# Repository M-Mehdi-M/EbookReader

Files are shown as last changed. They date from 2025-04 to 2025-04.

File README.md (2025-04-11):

## MAHMOUDI Mohammadmehdi 332CB 

# Description
EbookReader is an open-source hardware development platform featuring an E-Paper display, environmental sensing, and low-power connectivity options. Perfect for IoT projects, information displays, and environmental monitoring applications.

## 📋 Overview
This project provides a complete hardware platform built around the ESP32-C6 microcontroller with built-in WiFi 6 and Bluetooth 5 LE connectivity. The E-Paper display offers excellent visibility in various lighting conditions with minimal power consumption.

## 🔌 Hardware Architecture and Components

- **Microcontroller**: ESP32-C6-WROOM-1-N8
  - RISC-V core with WiFi 6 and Bluetooth 5 LE
  - Operating at 3.3V

- **Display**: E-Paper display module
  - SPI interface
  - Ultra-low power consumption when not refreshing

- **Storage**: 
  - microSD card slot (SPI)
  - 64MB External NOR Flash (W25Q512JVEIQ)

- **Sensors**:
  - BME688 Environmental sensor (temperature, humidity, pressure, gas)
  - Battery voltage monitoring

- **Power Management**:
  - Li-Po battery charging circuit
  - Fuel gauge (MAX17048G+T10)
  - Low dropout regulator (XC6220A331MR-G)
  - Deep sleep current <10μA

- **Timekeeping**:
  - DS3231SN RTC with temperature compensation

### Expansion Options
- Qwiic/Stemma QT connector for I²C peripherals
- Test pads for debugging

## 🔧 Development Guide

### Getting Started
1. Install the ESP-IDF development framework
2. Clone this repository
3. Connect the board via USB-C
4. Build and flash using ESP-IDF commands

### Example Applications
- Weather station
- Calendar display
- E-ink dashboard
- IoT sensor node
- Low-power data logger

## 📐 Hardware Design Files
The hardware design includes:
- Schematic
- PCB layout
- Bill of Materials
- 3D models of critical components

### Design Notes
- ESD protection on all external interfaces
- Carefully designed power distribution
- Signal integrity considerations for SPI bus
- Separate power domain for E-Paper

## 🔋 Battery Management
- Built-in Li-ion battery charging
- Battery level monitoring
- Low-battery detection and safe shutdown
- Optimized power design for long battery life

## 🛠️ Implementation Steps
1. Review schematic and understand all interfaces
2. Generate PCB layout from schematic
3. Implement power planes and critical routing
4. Add custom design rules for manufacturing
5. Place and route all signals
6. Add 3D models for visualization and mechanical fit

## ✅ Safety Features
- Overcurrent protection
- Reverse polarity protection
- ESD protection on external interfaces
- Thermal management for charging circuit

You can view the "BOM" file [here](Manufacturing/BOM.csv)

You can view the "PICK and PLACE" file [here](Manufacturing/Pick_&_Place.csv)

## 📖 Resources
- [Design & Implementation Guide](https://ocw.cs.pub.ro/courses/tsc/proiect2025)
- [ESP32-C6 Datasheet](https://www.espressif.com/sites/default/files/documentation/esp32-c6_datasheet_en.pdf)

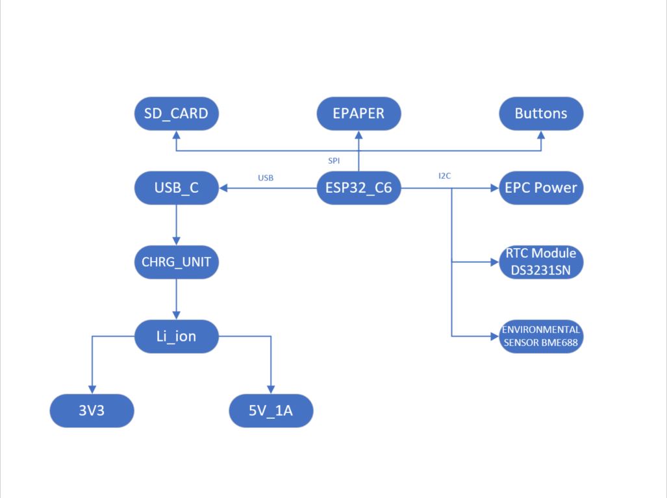
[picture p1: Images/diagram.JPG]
Diagram Image


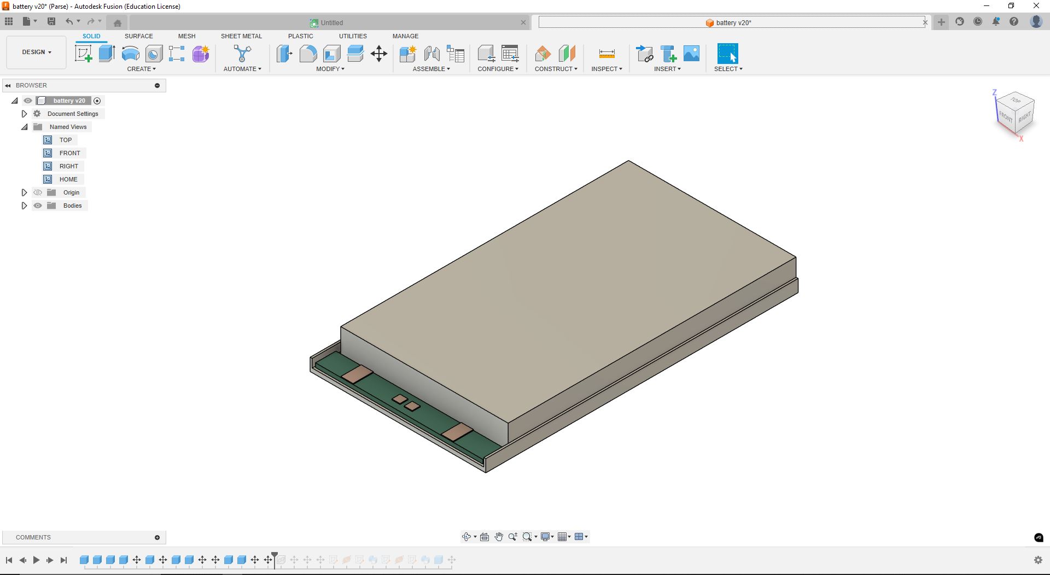
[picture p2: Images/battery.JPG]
Battery Image


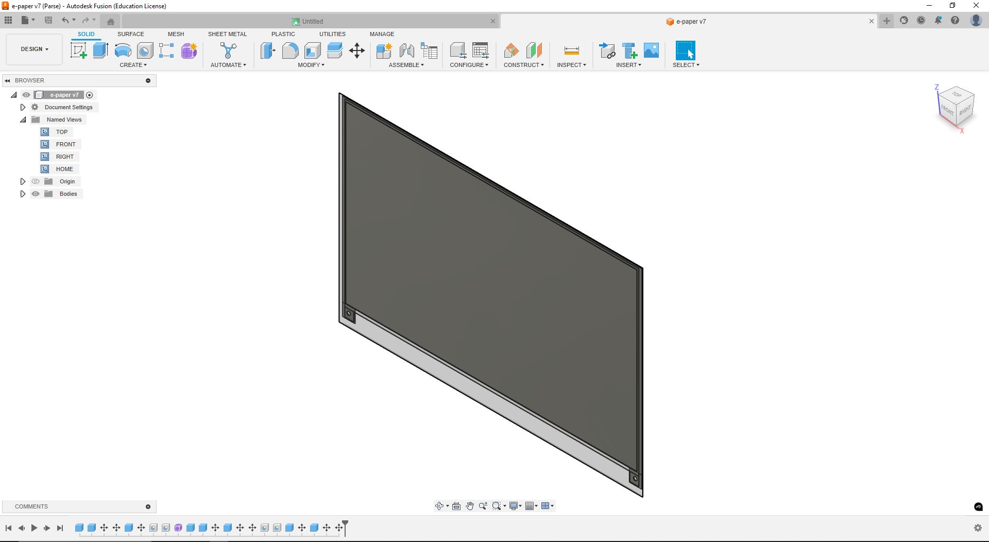
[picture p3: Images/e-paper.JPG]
E_paper Image


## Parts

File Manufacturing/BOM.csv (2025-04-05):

Qty | Value | Device | Package | Parts | Description | ARROW_PART_NUMBER | ARROW_PRICE-STOCK | AVAILABILITY | CENTROID_NOT_SPECIFIED | CHECK_PRICES | COPYRIGHT | DATASHEET | DESCRIPTION | DIGIKEY_DESCRIPTION | DIGIKEY_PART_NUMBER | HEIGHT | LEAD_FREE | MANUFACTURER_NAME | MANUFACTURER_PART_NUMBER | MF | MFR_NAME | MOUSER_PART_NUMBER | MOUSER_PRICE-STOCK | MOUSER_TESTING_PART_NUMBER | MOUSER_TESTING_PRICE-STOCK | MP | MPN | PACKAGE | POPULARITY | PREFIX | PRICE | PROD_ID | PURCHASE-URL | ROHS | SNAPEDA_LINK | SPICEMODEL | SPICEPREFIX | TEMPERATURE_RANGE_HIGH | TEMPERATURE_RANGE_LOW | TP_SIGNAL_NAME | VALUE
1 |  | ADAFRUIT_LEDCHIP-LED0603 | ADAFRUIT_CHIP-LED0603 | CHG_LED | LED
1 |  | ESP32C6_VARISTORCN1812 | ESP32C6_VARISTOR_CT/CN1812 | PFMF.050.1 | VARISTOR |  |  |  |  |  |  |  |  |  |  |  |  |  |  |  |  |  |  |  |  |  |  |  | 0
1 |  | SAMACSYS_PARTS_USB4110-GF-A | SAMACSYS_PARTS_USB4110GFA | J2 | CONN USB 2.0 TYPE-C R/A SMT |  |  |  |  |  |  |  | CONN USB 2.0 TYPE-C R/A SMT |  |  | 3.26mm |  | GCT (GLOBAL CONNECTOR TECHNOLOGY) | USB4110-GF-A |  |  | 640-USB4110-GF-A | https://www.mouser.co.uk/ProductDetail/GCT/USB4110-GF-A?qs=KUoIvG%2F9IlYiZvIXQjyJeA%3D%3D
1 |  | SJ | SJ | SJ1 | SMD solder JUMPER |  |  |  |  |  |  |  |  |  |  |  |  |  |  |  |  |  |  |  |  |  |  |  | 3
1 | 100nF | ESP32_WROVER_EAGLE-LTSPICE_CC0402 | ESP32_WROVER_EAGLE-LTSPICE_C0402 | C10 | CAPACITOR, European symbol |  |  |  |  |  |  |  |  |  |  |  |  |  |  |  |  |  |  |  |  |  |  |  |  |  |  |  |  |  |  | NONE | C
1 | 0.1uF/50V | ESP32_WROVER_EAGLE-LTSPICE_CC0402 | ESP32_WROVER_EAGLE-LTSPICE_C0402 | EPD_C5 | CAPACITOR, European symbol |  |  |  |  |  |  |  |  |  |  |  |  |  |  |  |  |  |  |  |  |  |  |  |  |  |  |  |  |  |  | NONE | C
1 | 0.47 | ESP32_WROVER_EAGLE-LTSPICE_RR0402 | ESP32_WROVER_EAGLE-LTSPICE_R0402 | R3 | RESISTOR, European symbol |  |  |  |  |  |  |  |  |  |  |  |  |  |  |  |  |  |  |  |  |  |  |  |  |  |  |  |  |  |  | NONE | R
1 | 100K | ESP32_WROVER_EAGLE-LTSPICE_RR0402 | ESP32_WROVER_EAGLE-LTSPICE_R0402 | R1_PWRUSB | RESISTOR, European symbol |  |  |  |  |  |  |  |  |  |  |  |  |  |  |  |  |  |  |  |  |  |  |  |  |  |  |  |  |  |  | NONE | R
1 | 100nF | EAGLE-LTSPICE_CC0402 | EAGLE-LTSPICE_C0402 | C4_USB | CAPACITOR, European symbol |  |  |  |  |  |  |  |  |  |  |  |  |  |  |  |  |  |  |  |  |  |  |  |  |  |  |  |  |  |  | NONE | C
6 | 100nF | ESP32_WROVER_EAGLE-LTSPICE_CC0402 | ESP32_WROVER_EAGLE-LTSPICE_C0402 | C1, C2, C6, C8, C9, C_DELAY | CAPACITOR, European symbol |  |  |  |  |  |  |  |  |  |  |  |  |  |  |  |  |  |  |  |  |  |  |  |  |  |  |  |  |  |  | NONE | C
1 | 100uF TANT | RCL_CPOL-EUCT3528 | RCL_CT3528 | C3 | POLARIZED CAPACITOR, European symbol |  |  |  |  |  |  |  |  |  |  |  |  |  |  |  |  |  |  |  |  |  |  |  | 0 |  |  |  |  |  |  |  | C
16 | 10K | ESP32_WROVER_EAGLE-LTSPICE_RR0402 | ESP32_WROVER_EAGLE-LTSPICE_R0402 | R1, R1_PINH, R1_PINH1, R2-PINH, R2-PINH1, R4, R5, R6, R7, R8, R9, R10, R_BOOT, R_CHANGE, R_CL1, R_RESET | RESISTOR, European symbol |  |  |  |  |  |  |  |  |  |  |  |  |  |  |  |  |  |  |  |  |  |  |  |  |  |  |  |  |  |  | NONE | R
1 | 10uF | ESP32_WROVER_EAGLE-LTSPICE_CC0402 | ESP32_WROVER_EAGLE-LTSPICE_C0402 | C7 | CAPACITOR, European symbol |  |  |  |  |  |  |  |  |  |  |  |  |  |  |  |  |  |  |  |  |  |  |  |  |  |  |  |  |  |  | NONE | C
1 | 112A-TAAR-R03_ATTEND | 112A-TAAR-R03_ATTEND | 112ATAARR03ATTEND | J4 | Micro SD Card Socket, Push-Push Type, Top Mount, SMT, H=1.83mm, 10u |  |  |  |  |  |  |  | Micro SD Card Socket | Push-Push Type | Top Mount | SMT | H=1.83mm | 10u |  |  | 1.9mm |  | ATTEND | 112A-TAAR-R03 ATTEND
1 | 15 | ESP32_WROVER_EAGLE-LTSPICE_RR0402 | ESP32_WROVER_EAGLE-LTSPICE_R0402 | R_CAPACITOR | RESISTOR, European symbol |  |  |  |  |  |  |  |  |  |  |  |  |  |  |  |  |  |  |  |  |  |  |  |  |  |  |  |  |  |  | NONE | R
1 | 1uF | ESP32_WROVER_EAGLE-LTSPICE_CC0402 | ESP32_WROVER_EAGLE-LTSPICE_C0402 | C5 | CAPACITOR, European symbol |  |  |  |  |  |  |  |  |  |  |  |  |  |  |  |  |  |  |  |  |  |  |  |  |  |  |  |  |  |  | NONE | C
9 | 1uF/50V | ESP32_WROVER_EAGLE-LTSPICE_CC0402 | ESP32_WROVER_EAGLE-LTSPICE_C0402 | EPD_C1, EPD_C2, EPD_C6, EPD_C7, EPD_C8, EPD_C9, EPD_C10, EPD_C11, EPD_C12 | CAPACITOR, European symbol |  |  |  |  |  |  |  |  |  |  |  |  |  |  |  |  |  |  |  |  |  |  |  |  |  |  |  |  |  |  | NONE | C
1 | 2.2 | ESP32_WROVER_EAGLE-LTSPICE_RR0402 | ESP32_WROVER_EAGLE-LTSPICE_R0402 | R2 | RESISTOR, European symbol |  |  |  |  |  |  |  |  |  |  |  |  |  |  |  |  |  |  |  |  |  |  |  |  |  |  |  |  |  |  | NONE | R
1 | 200 | ESP32_WROVER_EAGLE-LTSPICE_RR0402 | ESP32_WROVER_EAGLE-LTSPICE_R0402 | R1_BAT | RESISTOR, European symbol |  |  |  |  |  |  |  |  |  |  |  |  |  |  |  |  |  |  |  |  |  |  |  |  |  |  |  |  |  |  | NONE | R
2 | 20V/4.2A/52mO/1.4W | ESP32_WROVER_SPARKFUN-DISCRETESEMI_MOSFET_PCH-DMG2305UX-7 | ESP32_WROVER_SPARKFUN-DISCRETESEMI_SOT23-3 | Q1, Q2 | P-channel MOSFETs |  |  |  |  |  |  |  |  |  |  |  |  |  |  |  |  |  |  |  |  |  |  |  |  |  |  | TRAN-14388 |  |  |  |  |  |  |  |  | 20V/4.2A/52mO/1.4W
1 | 2K | ESP32_WROVER_EAGLE-LTSPICE_RR0402 | ESP32_WROVER_EAGLE-LTSPICE_R0402 | R2_BAT | RESISTOR, European symbol |  |  |  |  |  |  |  |  |  |  |  |  |  |  |  |  |  |  |  |  |  |  |  |  |  |  |  |  |  |  | NONE | R
3 | 4.7uF | EAGLE-LTSPICE_CC0402 | EAGLE-LTSPICE_C0402 | C1_BAT1, C1_BAT2, C5_USB | CAPACITOR, European symbol |  |  |  |  |  |  |  |  |  |  |  |  |  |  |  |  |  |  |  |  |  |  |  |  |  |  |  |  |  |  | NONE | C
2 | 4.7uF | ESP32_WROVER_EAGLE-LTSPICE_CC0402 | ESP32_WROVER_EAGLE-LTSPICE_C0402 | C1_BAT, C2_BAT | CAPACITOR, European symbol |  |  |  |  |  |  |  |  |  |  |  |  |  |  |  |  |  |  |  |  |  |  |  |  |  |  |  |  |  |  | NONE | C
1 | 4.7uF/25V | ESP32_WROVER_EAGLE-LTSPICE_CC0402 | ESP32_WROVER_EAGLE-LTSPICE_C0402 | C4 | CAPACITOR, European symbol |  |  |  |  |  |  |  |  |  |  |  |  |  |  |  |  |  |  |  |  |  |  |  |  |  |  |  |  |  |  | NONE | C
2 | 5k1 | ESP32_WROVER_EAGLE-LTSPICE_RR0402 | ESP32_WROVER_EAGLE-LTSPICE_R0402 | R2-USB, R2-USB1 | RESISTOR, European symbol |  |  |  |  |  |  |  |  |  |  |  |  |  |  |  |  |  |  |  |  |  |  |  |  |  |  |  |  |  |  | NONE | R
1 | 68uH | 744043680IND_4828-WE-TPC_WRE | IND_4828-WE-TPC_WRE | L1 |  |  |  |  |  |  | Copyright (C) 2024 Ultra Librarian. All rights reserved. |  |  |  |  |  |  |  | 744043680 |  | Wurth Electronics
1 | BD5229G-TR | BD5229G-TR | SOT95P280X125-5N | IC1 | Voltage Detector with Adjustable Delay Time: CMOS processes are utilized to develop high precision, low current consumption CMOS reset ICs that allow arbitrary setting of the delay time. The extensive lineup includes both Nch Open Drain and CMOS output types in a wide range of detection voltages (from 2.3V to 6.0V, in 0.1V steps), enabling selection of the ideal solution based on customer requirements. In addition, the entire series is of course both lead-free and RoHS-compliant. |  |  |  |  |  |  |  | Voltage Detector with Adjustable Delay Time: CMOS processes are utilized to develop high precision | low current consumption CMOS reset ICs that allow arbitrary setting of the delay time. The extensive lineup includes both Nch Open Drain and CMOS output types in a wide range of detection voltages (from 2.3V to 6.0V | in 0.1V steps) | enabling selection of the ideal solution based on customer requirements. In addition | the entire series is of course both lead-free and RoHS-compliant. |  |  | 1.25mm |  | ROHM Semiconductor | BD5229G-TR |  |  | 755-BD5229G-TR | https://www.mouser.co.uk/ProductDetail/ROHM-Semiconductor/BD5229G-TR?qs=4kLU8WoGk0vvnhrrYwdszw%3D%3D
1 | BME680 | ESP32_WROVER_BME680_BME680 | ESP32_WROVER_BME680_PSON80P300X300X100-8N | SENSOR2 | Integrated Environmental Unit |  |  | Unavailable |  |  |  |  | Integrated Environmental Unit |  |  |  |  |  |  | Bosch Sensortec |  |  |  |  |  | BME680 |  | LGA-8 Bosch Tools |  |  | None
2 | BUTTON_CUSYOMV1 | BUTTON_CUSYOMV1 | MYBUTTON | BOOT_BUTTON, CHANGE_BUTTON
1 | CPH3225A | CPH3225A | CAPCP3225X100N | C10_SUPERCAP | Cap 0.011F 3.3V 1210 Flat Check availability |  |  | Not in stock |  | https://www.snapeda.com/parts/CPH3225A/Seiko+Instruments/view-part/?ref=eda |  |  | 11 mF (EDLC) Supercapacitor 3.3 V 1210 (3225 Metric) - - |  |  |  |  |  |  | Seiko Instruments |  |  |  |  |  | CPH3225A |  | 1210 Seiko |  |  | None |  | https://www.snapeda.com/api/url_track_click_mouser/?unipart_id=562593&manufacturer=Seiko Instruments&part_name=CPH3225A&search_term=None |  | https://www.snapeda.com/parts/CPH3225A/Seiko+Instruments/view-part/?ref=snap
1 | DS3231SN# | DS3231SN# | SOIC127P1032X265-16N | U3 | Real Time Clock Serial 16-Pin SOIC W T/R Check availability |  |  | In Stock |  | https://www.snapeda.com/parts/DS3231SN%23/Analog+Devices/view-part/?ref=eda |  |  | Extremely Accurate I²C-Integrated RTC/TCXO/Crystal |  |  |  |  |  |  | Analog Devices |  |  |  |  |  | DS3231SN# |  | SOIC-16 Maxim |  |  | None |  | https://www.snapeda.com/api/url_track_click_mouser/?unipart_id=99048&manufacturer=Analog Devices&part_name=DS3231SN#&search_term=None |  | https://www.snapeda.com/parts/DS3231SN%23/Analog+Devices/view-part/?ref=snap
1 | ESP32-C6-WROOM-1-N8 | ESP32-C6-WROOM-1-N8 | XCVR_ESP32-C6-WROOM-1-N8 | U2 | Check availability |  |  | In Stock |  | https://www.snapeda.com/parts/ESP32-C6-WROOM-1-N8/Espressif+Systems/view-part/?ref=eda |  |  | Multiprotocol Modules ESP32-C6 module | Wi-Fi 6 in 2.4 GHz band | Bluetooth 5 | Zigbee 3.0 and Thread. ESP34-WROOM Compatible - ENGINEERING SAMPLE |  |  |  |  |  |  | Espressif Systems |  |  |  |  |  | ESP32-C6-WROOM-1-N8 |  | None |  |  | None |  |  |  | https://www.snapeda.com/parts/ESP32-C6-WROOM-1-N8/Espressif+Systems/view-part/?ref=snap
1 | ESP32_WROVER_AVX---SD0805S020S1R0_AVX_SD0805S020S1R0_0_0AVX_SD0805S020S1R0_0_0 | ESP32_WROVER_AVX---SD0805S020S1R0_AVX_SD0805S020S1R0_0_0AVX_SD0805S020S1R0_0_0 | ESP32_WROVER_AVX---SD0805S020S1R0_AVX_SD0805S020S1R0_0 | D2 | Schottky Barrier Rectifier Diode |  |  |  | No |  |  | http://datasheets.avx.com/schottky.pdf |  | DIODE SCHOTTKY 20V 1A 0805 | 478-7800-1-ND |  | yes |  |  | AVX |  | 581-SD0805S020S1R0 |  |  |  |  |  | 0805 (2012 metric) |  | D |  |  |  | yes |  |  |  | +125°C | -55°C
1 | ESP32_WROVER_SPARKFUN-IC-POWER_MCP73831 | ESP32_WROVER_SPARKFUN-IC-POWER_MCP73831 | ESP32_WROVER_SPARKFUN-IC-POWER_SOT23-5 | MCP73831 | MCP73831T Li-Ion, Li-Pol Controller |  |  |  |  |  |  |  |  |  |  |  |  |  |  |  |  |  |  |  |  |  |  |  |  |  |  | IC-09995
1 | FH34SRJ-24S-0.5SH_99_ | FH34SRJ-24S-0.5SH_99_ | FH34SRJ24S05SH99 | J1 | (0.50mm) Surface Mount, Right Angle |  |  |  |  |  |  |  | 24 Position FFC | FPC Connector Contacts | (0.50mm) Surface Mount | Right Angle |  |  | 1.1mm |  | Hirose | FH34SRJ-24S-0.5SH(99) |  |  | 798-FH34SRJ24S05SH99 | https://www.mouser.co.uk/ProductDetail/Hirose-Connector/FH34SRJ-24S-0.5SH99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
1 | MAX17048G+T10 | MAX17048G+T10 | SON50P200X200X80-9N | U4 | Check availability |  |  | In Stock |  | https://www.snapeda.com/parts/MAX17048G+T10/Analog+Devices/view-part/?ref=eda |  |  | 3µA 1-Cell/2-Cell Fuel Gauge with ModelGauge |  |  |  |  |  |  | Analog Devices |  |  |  |  |  | MAX17048G+T10 |  | TDFN-8 Maxim |  |  | None |  | https://www.snapeda.com/api/url_track_click_mouser/?unipart_id=329239&manufacturer=Analog Devices&part_name=MAX17048G+T10&search_term=None |  | https://www.snapeda.com/parts/MAX17048G+T10/Analog+Devices/view-part/?ref=snap
3 | MBR0530 | MBR0530 | SOD3716X135N | D3, D4, D5 | ON SEMICONDUCTOR - MBR0530 - DIODE, SCHOTTKY, 0.5A, 30V, SOD-123 |  |  | In Stock |  | https://www.snapeda.com/parts/MBR0530/Onsemi/view-part/?ref=eda |  |  | Diode Schottky 30 V 500mA Surface Mount SOD-123 |  |  |  |  |  |  | ON Semiconductor |  |  |  |  |  | MBR0530 |  | SOD-123-2 ON Semiconductor |  |  | None |  | https://www.snapeda.com/api/url_track_click_mouser/?unipart_id=179458&manufacturer=ON Semiconductor&part_name=MBR0530&search_term=None |  | https://www.snapeda.com/parts/MBR0530/Onsemi/view-part/?ref=snap
6 | PGB1010603MR | PGB1010603MR | DIOC1608X36N | D6, D8, D9, D10, D11, D12 | Check availability |  |  | In Stock |  | https://www.snapeda.com/parts/PGB1010603MR/Littelfuse/view-part/?ref=eda |  |  | 150V (Typ) Clamp - Ipp Tvs Diode Surface Mount 0603 (1608 Metric) |  |  |  |  |  |  | Littelfuse Inc. |  |  |  |  |  | PGB1010603MR |  | 0603 Littelfuse Inc. |  |  | None |  | https://www.snapeda.com/api/url_track_click_mouser/?unipart_id=5659453&manufacturer=Littelfuse Inc.&part_name=PGB1010603MR&search_term=None |  | https://www.snapeda.com/parts/PGB1010603MR/Littelfuse/view-part/?ref=snap
1 | QWIIC_RIGHT_ANGLE | QWIIC_CONNECTORJS-1MM | JST04_1MM_RA | J3 | SparkFun I2C Standard Qwiic Connector |  |  |  |  |  |  |  |  |  |  |  |  |  |  |  |  |  |  |  |  |  |  |  |  |  |  | CONN-13694 |  |  |  |  |  |  |  |  | QWIIC_RIGHT_ANGLE
1 | RESET_BUTTON | BUTTON_CUSYOMV1 | MYBUTTON | RESET_BUTTON
1 | SD0805S020S1R0 | ESP32_WROVER_AVX---SD0805S020S1R0_AVX_SD0805S020S1R0_0_0AVX_SD0805S020S1R0_0_0 | ESP32_WROVER_AVX---SD0805S020S1R0_AVX_SD0805S020S1R0_0 | D7 | Schottky Barrier Rectifier Diode |  |  |  | No |  |  | http://datasheets.avx.com/schottky.pdf |  | DIODE SCHOTTKY 20V 1A 0805 | 478-7800-1-ND |  | yes |  |  | AVX |  | 581-SD0805S020S1R0 |  |  |  |  |  | 0805 (2012 metric) |  | D |  |  |  | yes |  |  |  | +125°C | -55°C
1 | SI1308EDL-T1-GE3 | SI1308EDL-T1-GE3 | SOT65P210X110-3N | Q3 | MOSFET N-Ch 30V 1.5A TrenchFET SC70 Vishay Si1308EDL-T1-GE3 N-channel MOSFET Transistor, 1.5 A, 30 V, 3-Pin SC-70 |  |  | In Stock |  | https://www.snapeda.com/parts/SI1308EDL-T1-GE3/Vishay+Siliconix/view-part/?ref=eda |  |  | Si1308EDL-T1-GE3 N-channel MOSFET Transistor | 1.5 A | 30 V | 3-Pin SC-70 | Siliconix / Vishay SI1308EDL-T1-GE3 |  |  |  |  |  |  | Vishay Siliconix |  |  |  |  |  | SI1308EDL-T1-GE3 |  | SOT-323 Vishay Semiconductor |  |  | None |  | https://www.snapeda.com/api/url_track_click_mouser/?unipart_id=274603&manufacturer=Vishay Siliconix&part_name=SI1308EDL-T1-GE3&search_term=None |  | https://www.snapeda.com/parts/SI1308EDL-T1-GE3/Vishay+Siliconix/view-part/?ref=snap
17 | TPTP20R | TPTP20R | TP20R | 3V3, EPD_3V3, EPD_3V3_C, EPD_BUSY, EPD_CS, EPD_DC, EPD_RST, GND, GND., INT_RTC, MISO, MOSI, RX, SCK, TX, VBAT, VBUS | Test pad |  |  |  |  |  |  |  |  |  |  |  |  |  |  |  |  |  |  |  |  |  |  |  | 2
1 | USBLC6-2SC6Y | USBLC6-2SC6Y | SOT95P280X145-6N | D1 | Low Cap. ESD Protection Auto SOT-23-6 STMicroelectronics USBLC6-2SC6Y, Dual Uni-Directional TVS Diode Array, 6-Pin SOT-23 |  |  | In Stock |  | https://www.snapeda.com/parts/USBLC6-2SC6Y/STMicroelectronics/view-part/?ref=eda |  |  | 17V Clamp 5A (8/20µs) Ipp Tvs Diode Surface Mount SOT-23-6 |  |  |  |  |  |  | STMicroelectronics |  |  |  |  |  | USBLC6-2SC6Y |  | SOT-23-6 STMicroelectronics |  |  | None |  |  |  | https://www.snapeda.com/parts/USBLC6-2SC6Y/STMicroelectronics/view-part/?ref=snap
1 | W25Q512JVEIQ | W25Q512JVEIQ | SON127P600X800X80-9N | U1 | Check availability |  |  | In Stock |  | https://www.snapeda.com/parts/W25Q512JVEIQ/Winbond+Electronics/view-part/?ref=eda |  |  | FLASH - NOR Memory IC 512Mb (64M x 8) SPI - Quad I/O 133 MHz 8-WSON (8x6) |  |  |  |  |  |  | Winbond Electronics |  |  |  |  |  | W25Q512JVEIQ |  | Package |  |  | None |  |  |  | https://www.snapeda.com/parts/W25Q512JVEIQ/Winbond+Electronics/view-part/?ref=snap
1 | XC6220A331MR-G | XC6220A331MR-G | SOT95P280X120-5N | IC4 | LDO Voltage Regulators |  |  |  |  |  |  |  | LDO Voltage Regulators |  |  | 1.2mm |  | Torex | XC6220A331MR-G |  |  | 865-XC6220A331MR-G | https://www.mouser.co.uk/ProductDetail/Torex-Semiconductor/XC6220A331MR-G?qs=AsjdqWjXhJ8ZSWznL1J0gg%3D%3D

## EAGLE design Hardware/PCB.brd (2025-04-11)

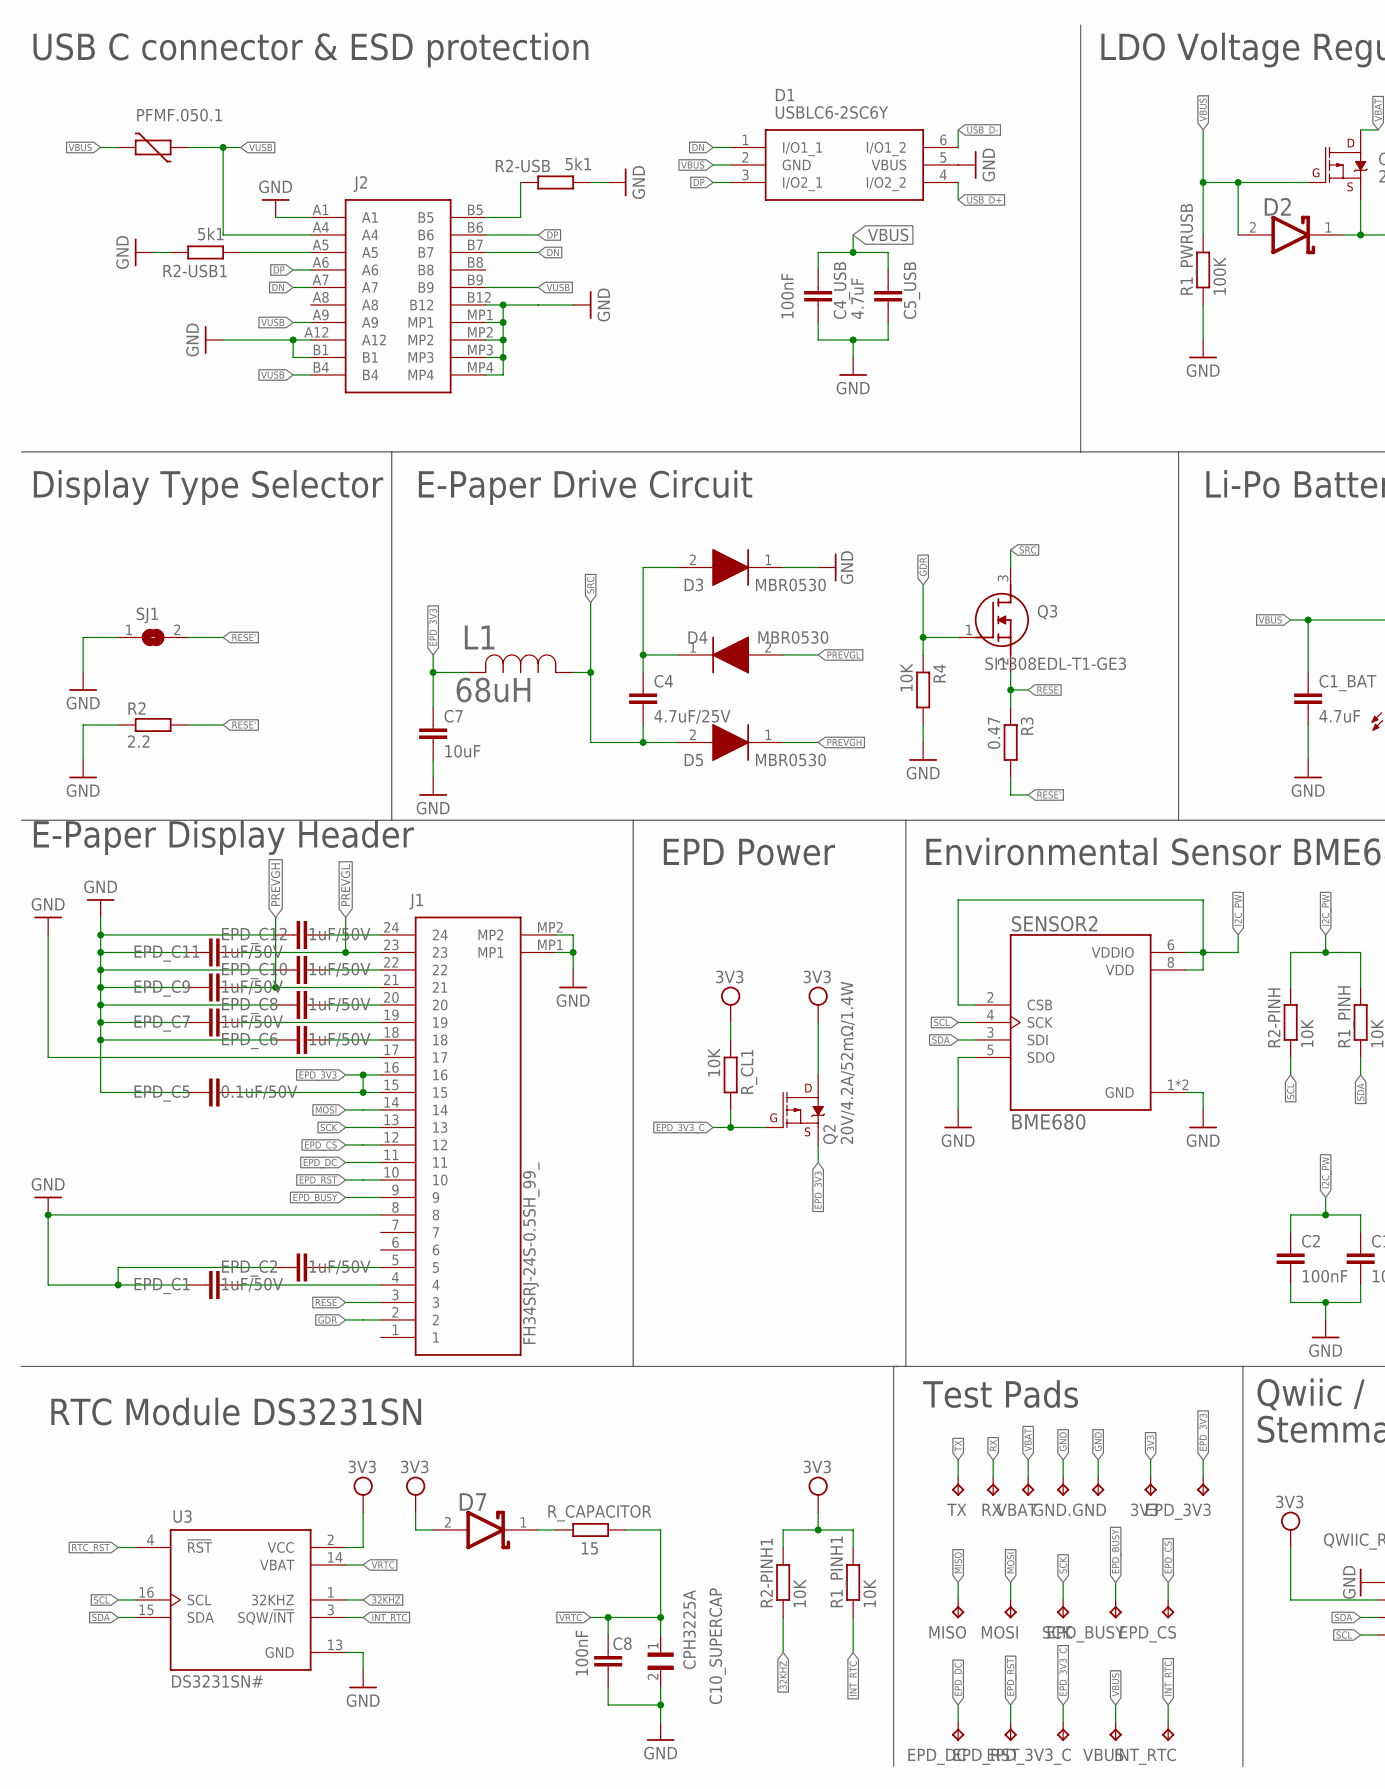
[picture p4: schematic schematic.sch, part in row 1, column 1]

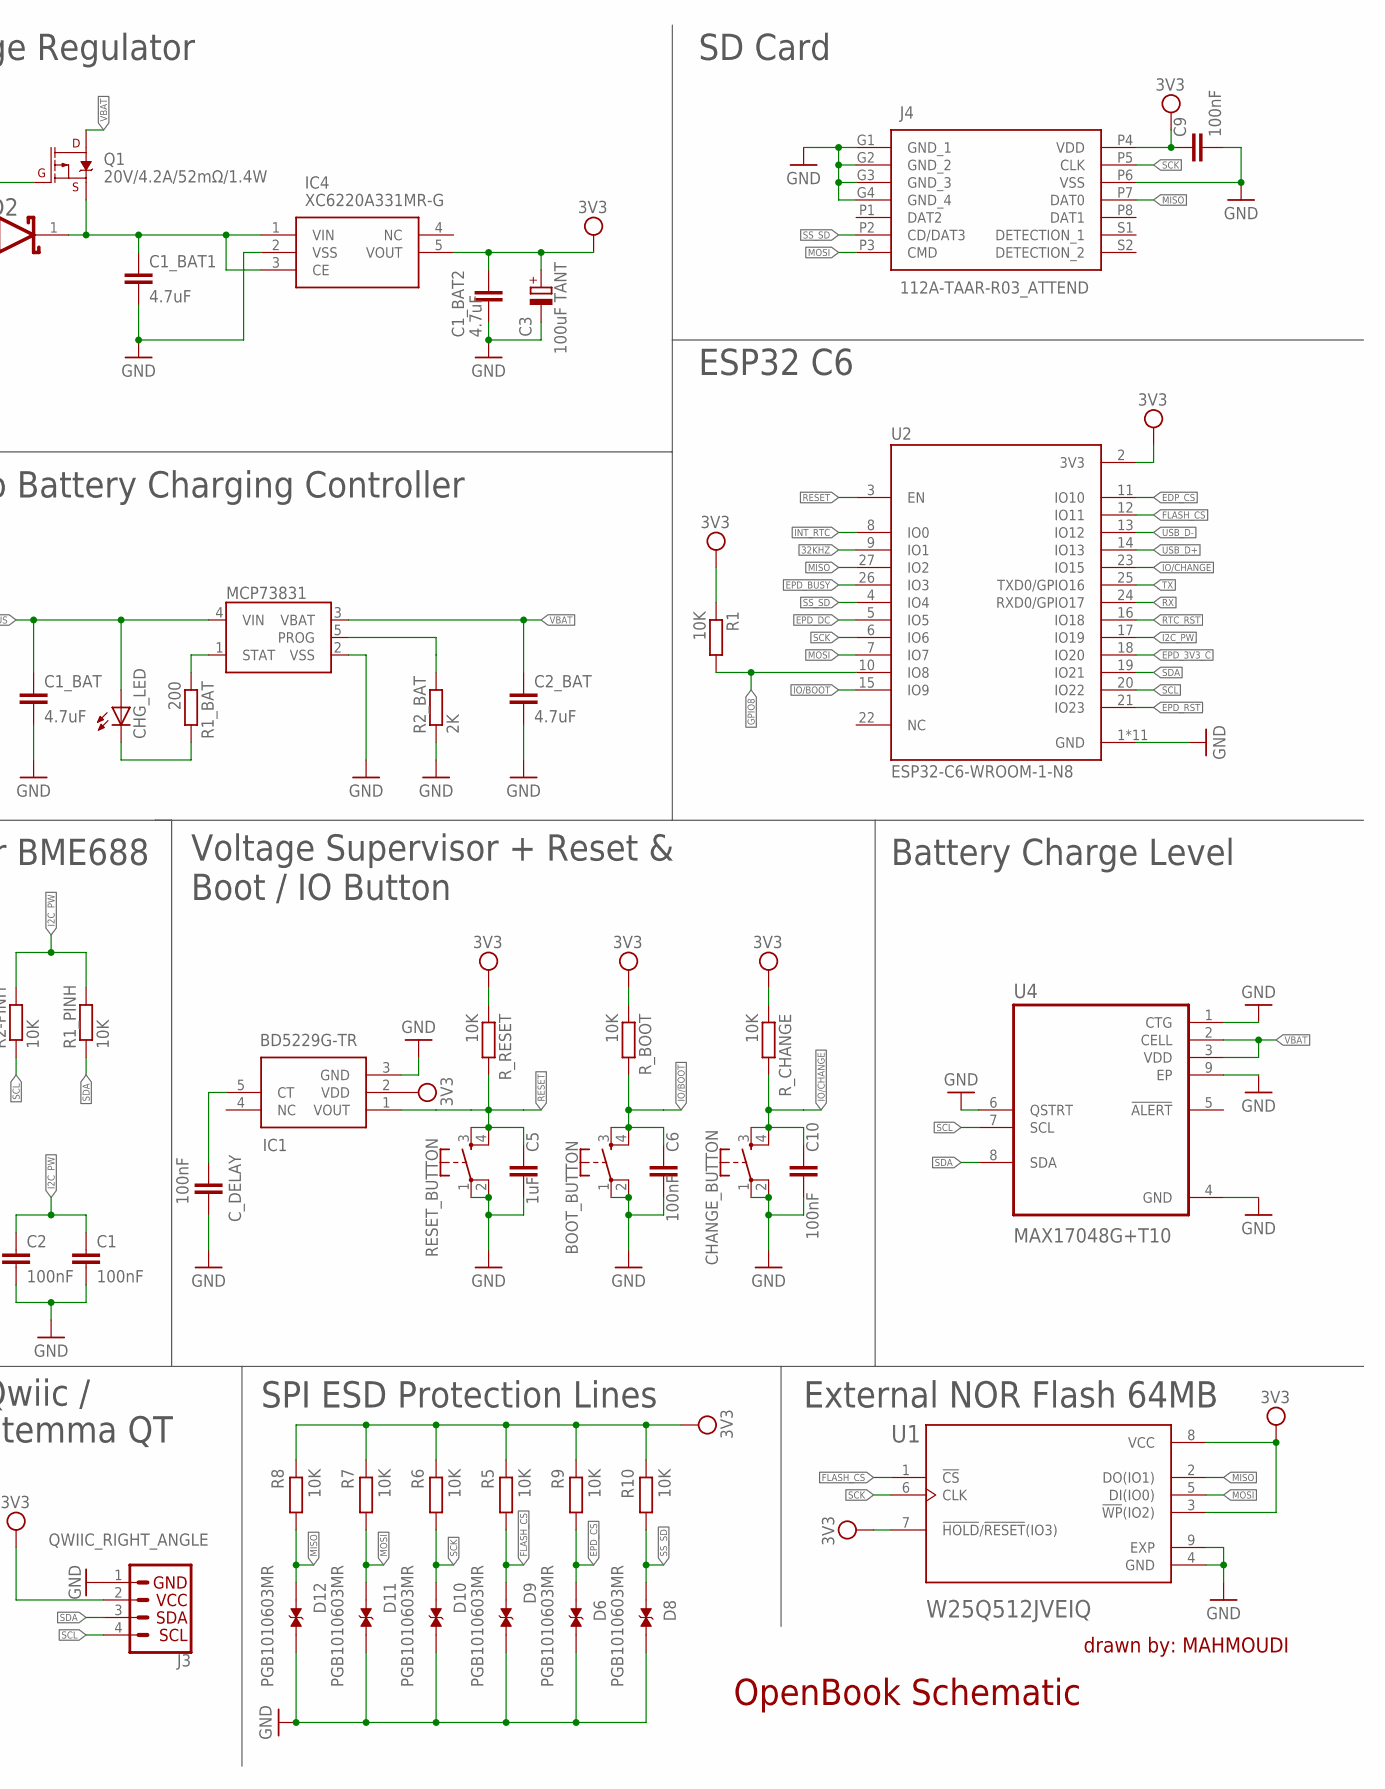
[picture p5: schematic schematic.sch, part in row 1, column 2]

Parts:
3V3: TPTP20R; TP20R
BOOT_BUTTON: BUTTON_CUSYOMV1; MYBUTTON
C1, C2, C6, C8, C9, C10: 100nF; ESP32_WROVER_EAGLE-LTSPICE_C0402
C1_BAT, C2_BAT: 4.7uF; ESP32_WROVER_EAGLE-LTSPICE_C0402
C1_BAT1, C1_BAT2, C5_USB: 4.7uF; EAGLE-LTSPICE_C0402
C3: 100uF TANT; RCL_CT3528
C4: 4.7uF/25V; ESP32_WROVER_EAGLE-LTSPICE_C0402
C4_USB: 100nF; EAGLE-LTSPICE_C0402
C5: 1uF; ESP32_WROVER_EAGLE-LTSPICE_C0402
C7: 10uF; ESP32_WROVER_EAGLE-LTSPICE_C0402
C10_SUPERCAP: CPH3225A; CAPCP3225X100N
CHANGE_BUTTON: BUTTON_CUSYOMV1; MYBUTTON
CHG_LED: ADAFRUIT_LEDCHIP-LED0603; ADAFRUIT_CHIP-LED0603
C_DELAY: 100nF; ESP32_WROVER_EAGLE-LTSPICE_C0402
D1: USBLC6-2SC6Y; SOT95P280X145-6N
D2: ESP32_WROVER_AVX---SD0805S020S1R0_AVX_SD0805S020S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; ESP32_WROVER_AVX---SD0805S020S1R0_AVX_SD0805S020S1R0_0
D3, D4, D5: MBR0530; SOD3716X135N
D6, D8, D9, D10, D11, D12: PGB1010603MR; DIOC1608X36N
D7: SD0805S020S1R0; ESP32_WROVER_AVX---SD0805S020S1R0_AVX_SD0805S020S1R0_0
EPD_3V3, EPD_3V3_C: TPTP20R; TP20R
EPD_BUSY: TPTP20R; TP20R
EPD_C1, EPD_C2, EPD_C6, EPD_C7, EPD_C8, EPD_C9, EPD_C10, EPD_C11, EPD_C12: 1uF/50V; ESP32_WROVER_EAGLE-LTSPICE_C0402
EPD_C5: 0.1uF/50V; ESP32_WROVER_EAGLE-LTSPICE_C0402
EPD_CS: TPTP20R; TP20R
EPD_DC: TPTP20R; TP20R
EPD_RST: TPTP20R; TP20R
GND, GND.: TPTP20R; TP20R
IC1: BD5229G-TR; SOT95P280X125-5N
IC4: XC6220A331MR-G; SOT95P280X120-5N
INT_RTC: TPTP20R; TP20R
J1: FH34SRJ-24S-0.5SH_99_; FH34SRJ24S05SH99
J2: SAMACSYS_PARTS_USB4110-GF-A; SAMACSYS_PARTS_USB4110GFA
J3: QWIIC_RIGHT_ANGLE; JST04_1MM_RA
J4: 112A-TAAR-R03_ATTEND; 112ATAARR03ATTEND
L1: 68uH; IND_4828-WE-TPC_WRE
MCP73831: ESP32_WROVER_SPARKFUN-IC-POWER_MCP73831; ESP32_WROVER_SPARKFUN-IC-POWER_SOT23-5
MISO: TPTP20R; TP20R
MOSI: TPTP20R; TP20R
PFMF.050.1: ESP32C6_VARISTORCN1812; ESP32C6_VARISTOR_CT/CN1812
Q1, Q2: 20V/4.2A/52mΩ/1.4W; ESP32_WROVER_SPARKFUN-DISCRETESEMI_SOT23-3
Q3: SI1308EDL-T1-GE3; SOT65P210X110-3N
R1, R1_PINH, R1_PINH1, R2-PINH, R2-PINH1, R4, R5, R6, R7, R8, R9, R10: 10K; ESP32_WROVER_EAGLE-LTSPICE_R0402
R1_BAT: 200; ESP32_WROVER_EAGLE-LTSPICE_R0402
R1_PWRUSB: 100K; ESP32_WROVER_EAGLE-LTSPICE_R0402
R2: 2.2; ESP32_WROVER_EAGLE-LTSPICE_R0402
R2-USB, R2-USB1: 5k1; ESP32_WROVER_EAGLE-LTSPICE_R0402
R2_BAT: 2K; ESP32_WROVER_EAGLE-LTSPICE_R0402
R3: 0.47; ESP32_WROVER_EAGLE-LTSPICE_R0402
RESET_BUTTON: RESET_BUTTON; MYBUTTON
RX: TPTP20R; TP20R
R_BOOT: 10K; ESP32_WROVER_EAGLE-LTSPICE_R0402
R_CAPACITOR: 15; ESP32_WROVER_EAGLE-LTSPICE_R0402
R_CHANGE: 10K; ESP32_WROVER_EAGLE-LTSPICE_R0402
R_CL1: 10K; ESP32_WROVER_EAGLE-LTSPICE_R0402
R_RESET: 10K; ESP32_WROVER_EAGLE-LTSPICE_R0402
SCK: TPTP20R; TP20R
SENSOR2: BME680; ESP32_WROVER_BME680_PSON80P300X300X100-8N
SJ1: SJ
TX: TPTP20R; TP20R
U1: W25Q512JVEIQ; SON127P600X800X80-9N
U2: ESP32-C6-WROOM-1-N8; XCVR_ESP32-C6-WROOM-1-N8
U3: DS3231SN#; SOIC127P1032X265-16N
U4: MAX17048G+T10; SON50P200X200X80-9N
VBAT: TPTP20R; TP20R
VBUS: TPTP20R; TP20R

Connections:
3V3: 3V3.TP, C1_BAT2.1, C3.+, C9.1, D7.2 (ANODE), IC1.2 (VDD), IC4.5 (VOUT), J3.2, J4.P4 (VDD), Q2.3 (D), R1.1, R1_PINH1.2, R2-PINH1.2, R5.1, R6.1, R7.1, R8.1, R9.1, R10.1, R_BOOT.1, R_CHANGE.1, R_CL1.1, R_RESET.1, U1.3 (!WP!(IO2)), U1.7 (!HOLD!/!RESET!(IO3)), U1.8 (VCC), U2.2 (3V3), U3.2 (VCC)
32KHZ: R2-PINH1.1, U2.9 (IO1), U3.1 (32KHZ)
DN: D1.1 (I/O1_1), J2.A7, J2.B7
DP: D1.3 (I/O2_1), J2.A6, J2.B6
EDP_CS: U2.11 (IO10)
EPD_3V3: C7.1, EPD_3V3.TP, EPD_C5.2, J1.15, J1.16, L1.2, Q2.2 (S)
EPD_3V3_C: EPD_3V3_C.TP, Q2.1 (G), R_CL1.2, U2.18 (IO20)
EPD_BUSY: EPD_BUSY.TP, J1.9, U2.26 (IO3)
EPD_CS: D6.1, EPD_CS.TP, J1.12, R9.2
EPD_DC: EPD_DC.TP, J1.11, U2.5 (IO5)
EPD_RST: EPD_RST.TP, J1.10, U2.21 (IO23)
FLASH_CS: D9.1, R5.2, U1.1 (!CS), U2.12 (IO11)
GDR: J1.2, Q3.1 (G), R4.1
GND: BOOT_BUTTON.1, BOOT_BUTTON.2, C1.2, C1_BAT.2, C1_BAT1.2, C1_BAT2.2, C2.2, C2_BAT.2, C3.-, C4_USB.2, C5.2, C5_USB.2, C6.2, C7.2, C8.2, C9.2, C10.2, C10_SUPERCAP.2, CHANGE_BUTTON.1, CHANGE_BUTTON.2, C_DELAY.2, D1.5 (VBUS), D3.1 (K), D6.2, D8.2, D9.2, D10.2, D11.2, D12.2, EPD_C1.1, EPD_C2.1, EPD_C5.1, EPD_C6.1, EPD_C7.1, EPD_C8.1, EPD_C9.1, EPD_C10.1, EPD_C11.1, EPD_C12.1, GND.TP, GND..TP, IC1.3 (GND), IC4.2 (VSS), J1.8, J1.17, J1.MP1, J1.MP2, J2.A1, J2.A12, J2.B1, J2.B12, J2.MP1, J2.MP2, J2.MP3, J2.MP4, J3.1, J4.G1 (GND_1), J4.G2 (GND_2), J4.G3 (GND_3), J4.G4 (GND_4), J4.P6 (VSS), MCP73831.2 (VSS), R1_PWRUSB.1, R2.1, R2-USB.2, R2-USB1.1, R2_BAT.1, R4.2, RESET_BUTTON.1, RESET_BUTTON.2, SENSOR2.1 (GND), SENSOR2.5 (SDO), SENSOR2.7 (GND), SJ1.1, U1.4 (GND), U1.9 (EXP), U2.1 (GND), U2.28 (GND), U2.29_1 (GND), U2.29_2 (GND), U2.29_3 (GND), U2.29_4 (GND), U2.29_5 (GND), U2.29_6 (GND), U2.29_7 (GND), U2.29_8 (GND), U2.29_9 (GND), U3.13 (GND), U4.1 (CTG), U4.4 (GND), U4.6 (QSTRT), U4.9 (EP)
GPIO8: R1.2, U2.10 (IO8)
I2C_PW: C1.1, C2.1, R1_PINH.2, R2-PINH.2, SENSOR2.2 (CSB), SENSOR2.6 (VDDIO), SENSOR2.8 (VDD), U2.17 (IO19)
INT_RTC: INT_RTC.TP, R1_PINH1.1, U2.8 (IO0), U3.3 (SQW/!INT)
IO/BOOT: BOOT_BUTTON.3, BOOT_BUTTON.4, C6.1, R_BOOT.2, U2.15 (IO9)
IO/CHANGE: C10.1, CHANGE_BUTTON.3, CHANGE_BUTTON.4, R_CHANGE.2, U2.23 (IO15)
MISO: D12.1, J4.P7 (DAT0), MISO.TP, R8.2, U1.2 (DO(IO1)), U2.27 (IO2)
MOSI: D11.1, J1.14, J4.P3 (CMD), MOSI.TP, R7.2, U1.5 (DI(IO0)), U2.7 (IO7)
unnamed: J2.B5, R2-USB.1
unnamed: J2.A5, R2-USB1.2
unnamed: EPD_C2.2, J1.5
unnamed: C1_BAT1.1, D2.1 (CATHODE), IC4.1 (VIN), IC4.3 (CE), Q1.2 (S)
unnamed: MCP73831.5 (PROG), R2_BAT.2
unnamed: MCP73831.1 (STAT), R1_BAT.1
unnamed: CHG_LED.C, R1_BAT.2
unnamed: C4.1, D3.2 (A), D4.1 (K)
unnamed: EPD_C1.2, J1.4
unnamed: EPD_C12.2, J1.24
unnamed: EPD_C10.2, J1.22
unnamed: EPD_C8.2, J1.20
unnamed: EPD_C7.2, J1.19
unnamed: EPD_C6.2, J1.18
unnamed: C_DELAY.1, IC1.5 (CT)
unnamed: D7.1 (CATHODE), R_CAPACITOR.2
PREVGH: D5.1 (K), EPD_C9.2, J1.21
PREVGL: D4.2 (A), EPD_C11.2, J1.23
RESE: J1.3, Q3.2 (S), R3.1
RESE': R2.2, R3.2, SJ1.2
RESET: C5.1, IC1.1 (VOUT), RESET_BUTTON.3, RESET_BUTTON.4, R_RESET.2, U2.3 (EN)
RTC_RST: U2.16 (IO18), U3.4 (!RST)
RX: RX.TP, U2.24 (RXD0/GPIO17)
SCK: D10.1, J1.13, J4.P5 (CLK), R6.2, SCK.TP, U1.6 (CLK), U2.6 (IO6)
SCL: J3.4, R2-PINH.1, SENSOR2.4 (SCK), U2.20 (IO22), U3.16 (SCL), U4.7 (SCL)
SDA: J3.3, R1_PINH.1, SENSOR2.3 (SDI), U2.19 (IO21), U3.15 (SDA), U4.8 (SDA)
SRC: C4.2, D5.2 (A), L1.1, Q3.3 (D)
SS_SD: D8.1, J4.P2 (CD/DAT3), R10.2, U2.4 (IO4)
TX: TX.TP, U2.25 (TXD0/GPIO16)
USB_D+: D1.4 (I/O2_2), U2.14 (IO13)
USB_D-: D1.6 (I/O1_2), U2.13 (IO12)
VBAT: C2_BAT.1, MCP73831.3 (VBAT), Q1.3 (D), U4.2 (CELL), U4.3 (VDD), VBAT.TP
VBUS: C1_BAT.1, C4_USB.1, C5_USB.1, CHG_LED.A, D1.2 (GND), D2.2 (ANODE), MCP73831.4 (VIN), PFMF.050.1.2, Q1.1 (G), R1_PWRUSB.2, VBUS.TP
VRTC: C8.1, C10_SUPERCAP.1, R_CAPACITOR.1, U3.14 (VBAT)
VUSB: J2.A4, J2.A9, J2.B4, J2.B9, PFMF.050.1.1

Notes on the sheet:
drawn by: MAHMOUDI
SD Card
ESP32 C6
USB C connector & ESD protection
LDO Voltage Regulator
Li-Po Battery Charging Controller
E-Paper Drive Circuit
Display Type Selector
RTC Module DS3231SN
Test Pads
Qwiic / Stemma QT
SPI ESD Protection Lines
External NOR Flash 64MB
OpenBook Schematic
E-Paper Display Header
EPD Power
Environmental Sensor BME688
Voltage Supervisor + Reset & Boot / IO Button
Battery Charge Level

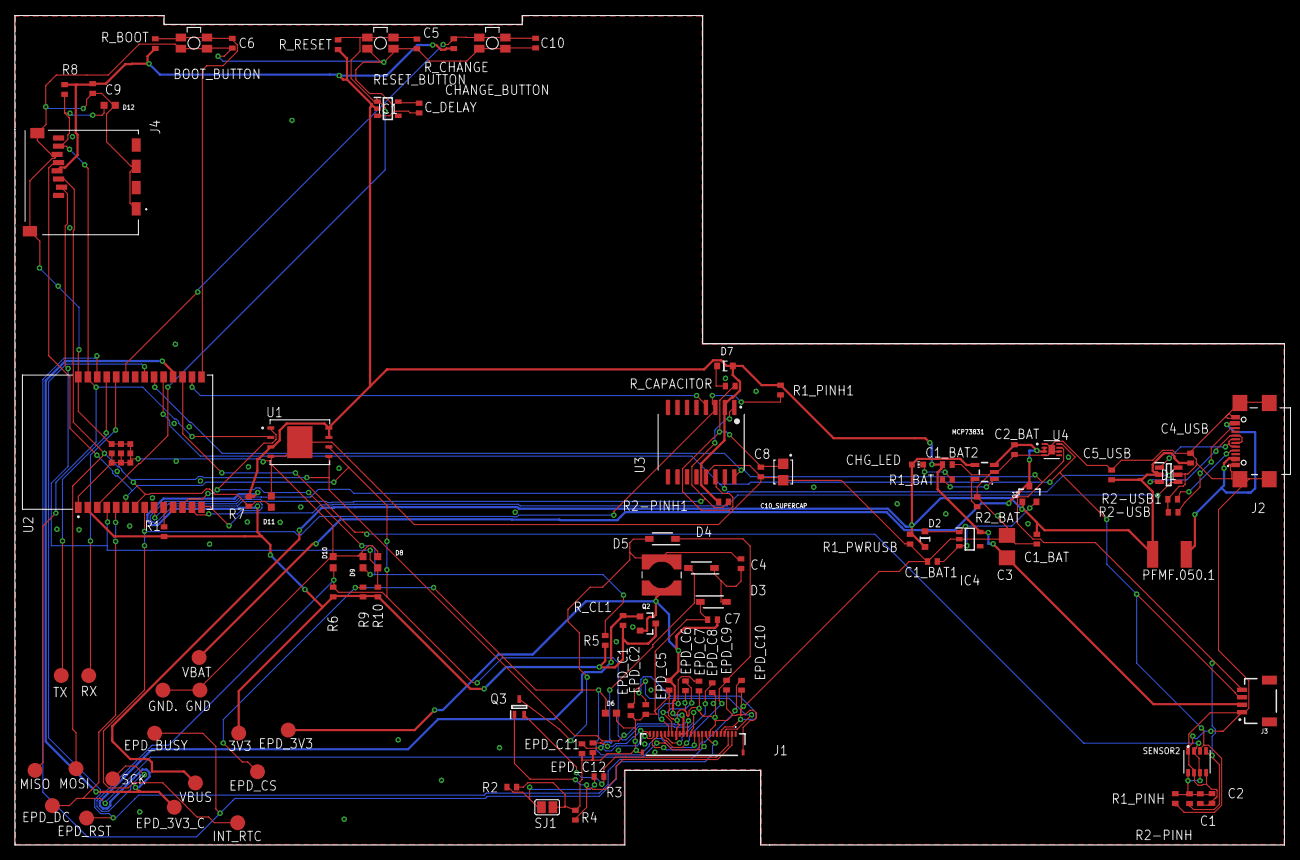
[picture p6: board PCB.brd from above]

Board: 2 copper layers, 170.2 x 111.2 mm, 103 parts (0 on the bottom side), 55 nets.

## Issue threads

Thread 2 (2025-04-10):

Lipsa frame-ului standard pentru schematic

bourbun, 2025-04-10:
Schematicul nu include in frame numele proiectului si autorul. Desi nu este obligatoriu, adaugarea unui astfel de frame ajuta la mentenanta.

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

M-Mehdi-M, 2025-04-11:
Am rezolvat problema

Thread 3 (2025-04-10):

Lipsa delimitari clare intre blocurile functionale din schematic

bourbun, 2025-04-10:
In schematic nu exista o delimitare vizuala clara a blocurilor functionale (ex: USB,LDO,ESP32,SD Card, Battery Management etc.). Desi nu este obligatoriu, este recomandat sa existe o organizare mai clara pentru a facilita intelegerea schemei electrice.
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

M-Mehdi-M, 2025-04-11:
Am rezolvat problema

Closed 2025-04-11.

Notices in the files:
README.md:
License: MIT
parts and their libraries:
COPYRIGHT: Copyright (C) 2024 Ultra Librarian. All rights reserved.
